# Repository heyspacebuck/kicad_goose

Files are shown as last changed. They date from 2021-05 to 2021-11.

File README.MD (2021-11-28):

# Horrible Goose Badge SAO

[@Gnarflordius](https://twitter.com/Gnarflordius) made a KiCad footprint of the Horrible Goose so I turned it into a set of capacitive-touch boards that function as [Simple Add-Ons](https://hackaday.com/2019/03/20/introducing-the-shitty-add-on-v1-69bis-standard/). All the boards are based on the [Atmel AT42QT101x chips](http://ww1.microchip.com/downloads/en/DeviceDoc/40001947A.pdf), which are out of stock everywhere right now. Sorry. If anyone has suggestions for alternate cap-touch sensors, or knows how to set up QTouch on an ATtiny, please drop me a line.

The `/kicad` folder is set up to contain multiple projects that each rely on `goose.lib` and `\goose.pretty` for schematic symbols and PCB footprints. These projects are:

### SAO 1: Horrible Goose Cap Touch Sensor

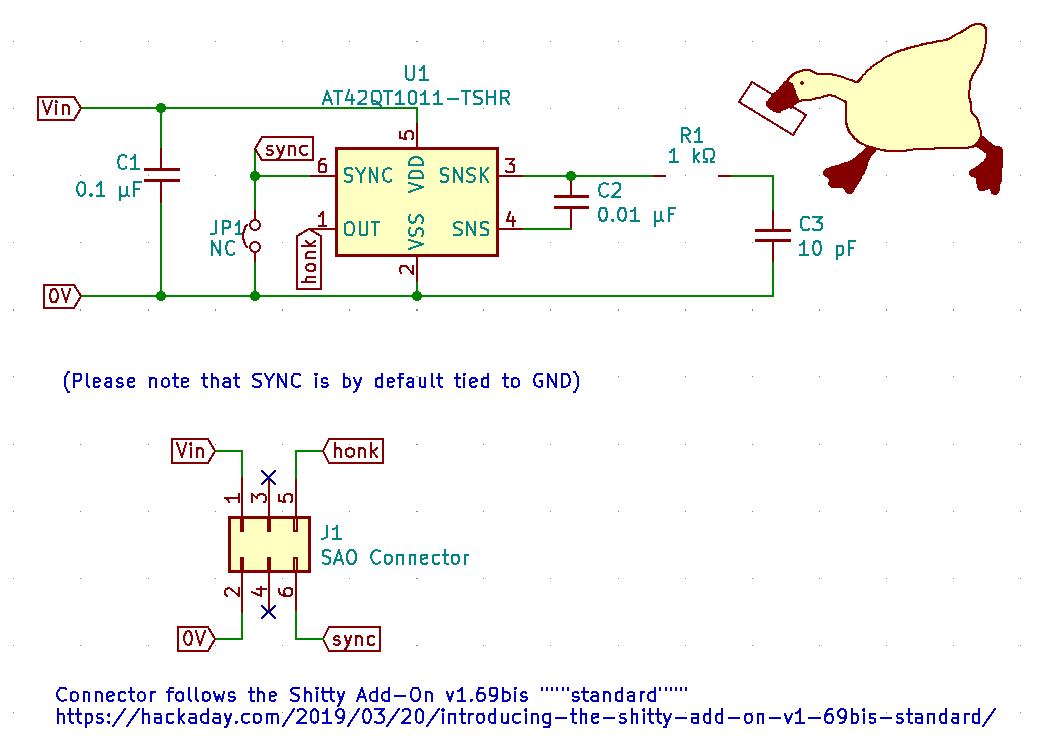
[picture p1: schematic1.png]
schematic

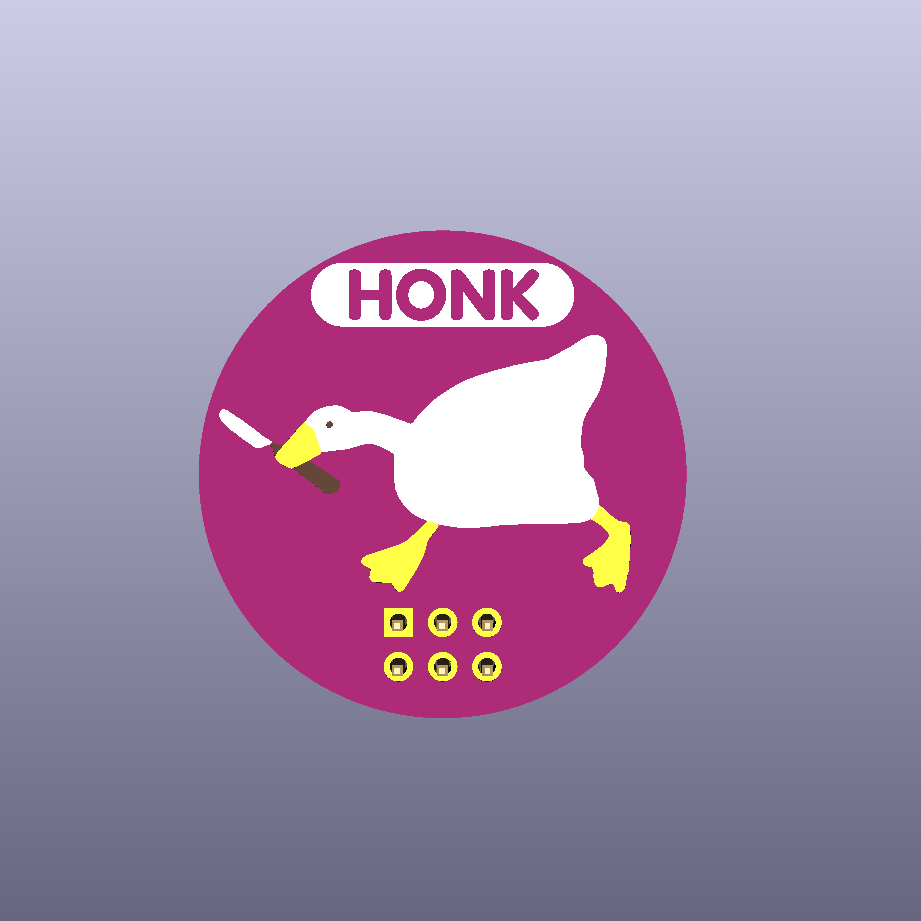
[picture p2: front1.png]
front render

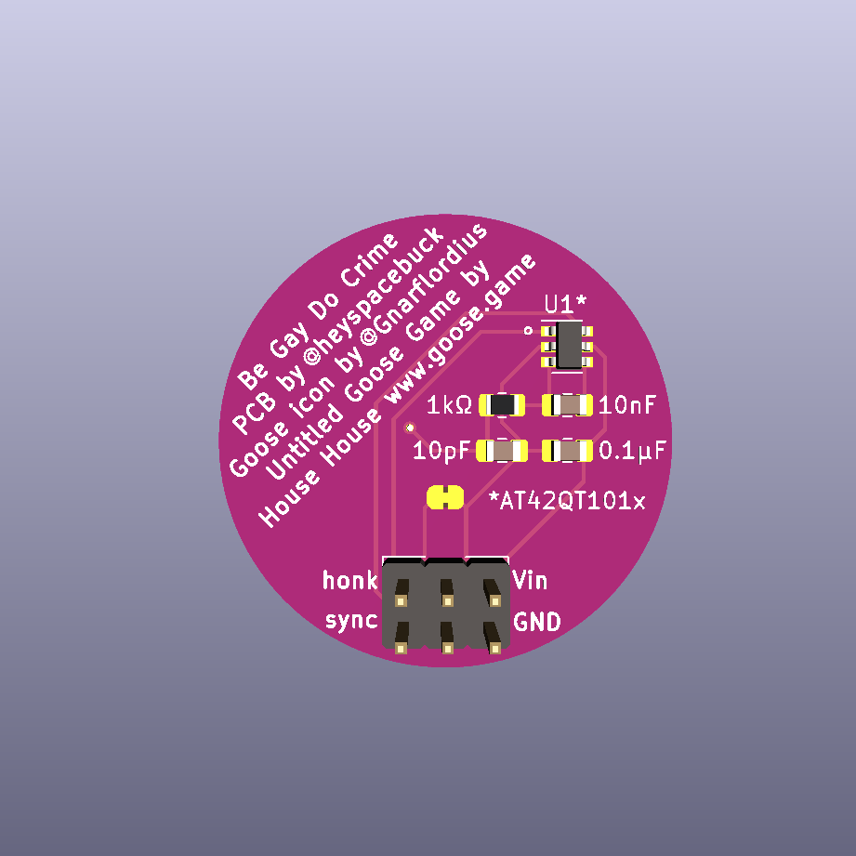
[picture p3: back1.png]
back render

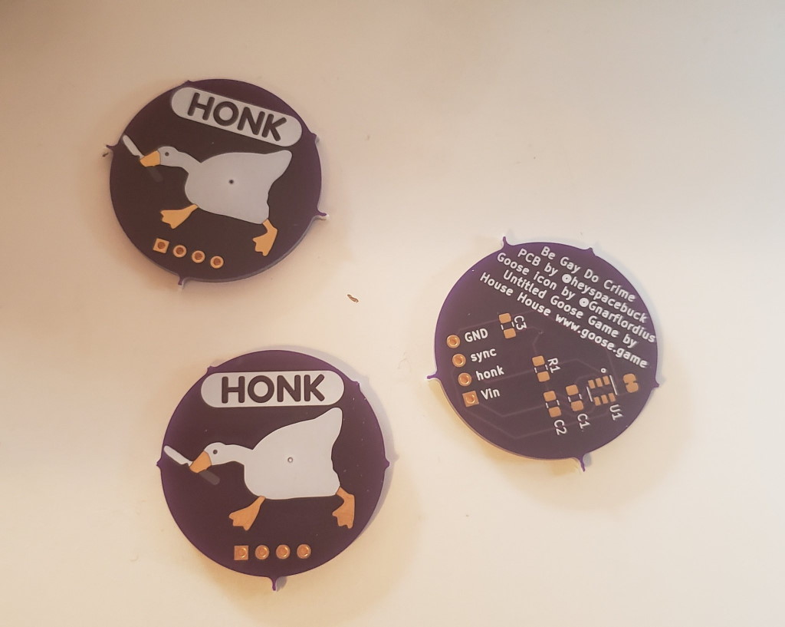
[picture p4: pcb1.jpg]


Here we see the basic SAO. You can find it in the `/kicad` folder under the name `SAO-captouch-sensor-only.pro`. The SCL and SDA lines are not needed; the HONK pin (GPIO1, by SAO naming conventions) connects to the sensor output; the SYNC pin (GPIO2) is by default tied to ground. When the goose is touched, the HONK pin is driven HIGH; otherwise, it is pulled LOW by an internal pull-down resistor. If for whatever reason you want to mess with the default SYNC settings, you can cut the jumper that ties it to ground and instead drive it via GPIO2.

You can see this circuit (with a non-SAO pinout) connected to an Arduino in [this tweet from back in May](https://twitter.com/heyspacebuck/status/1396235318634840066). The Arduino code being used is available in the `/code/arduino_honk` folder.

### SAO 2: Horrible Goose Cap Touch Sensor - After Dark

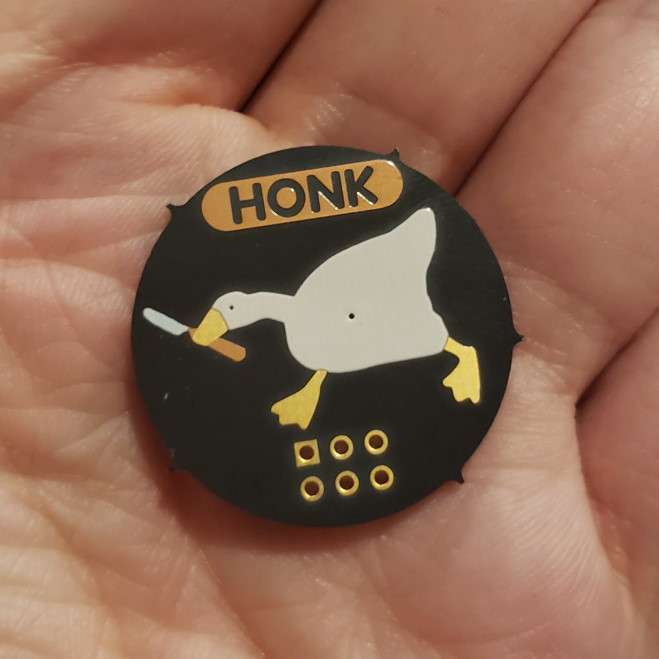
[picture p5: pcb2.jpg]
photo of an OSH Park After Dark PCB


This project is in the `kicad/` folder named `SAO-captouch-sensor-only-after-dark.pro`. It's the same circuit as above, but the "HONK" text and sensor footprint have been optimized for OSH Park's After Dark boards. 

### SAO 3: Horrible Goose, But Extra Evil

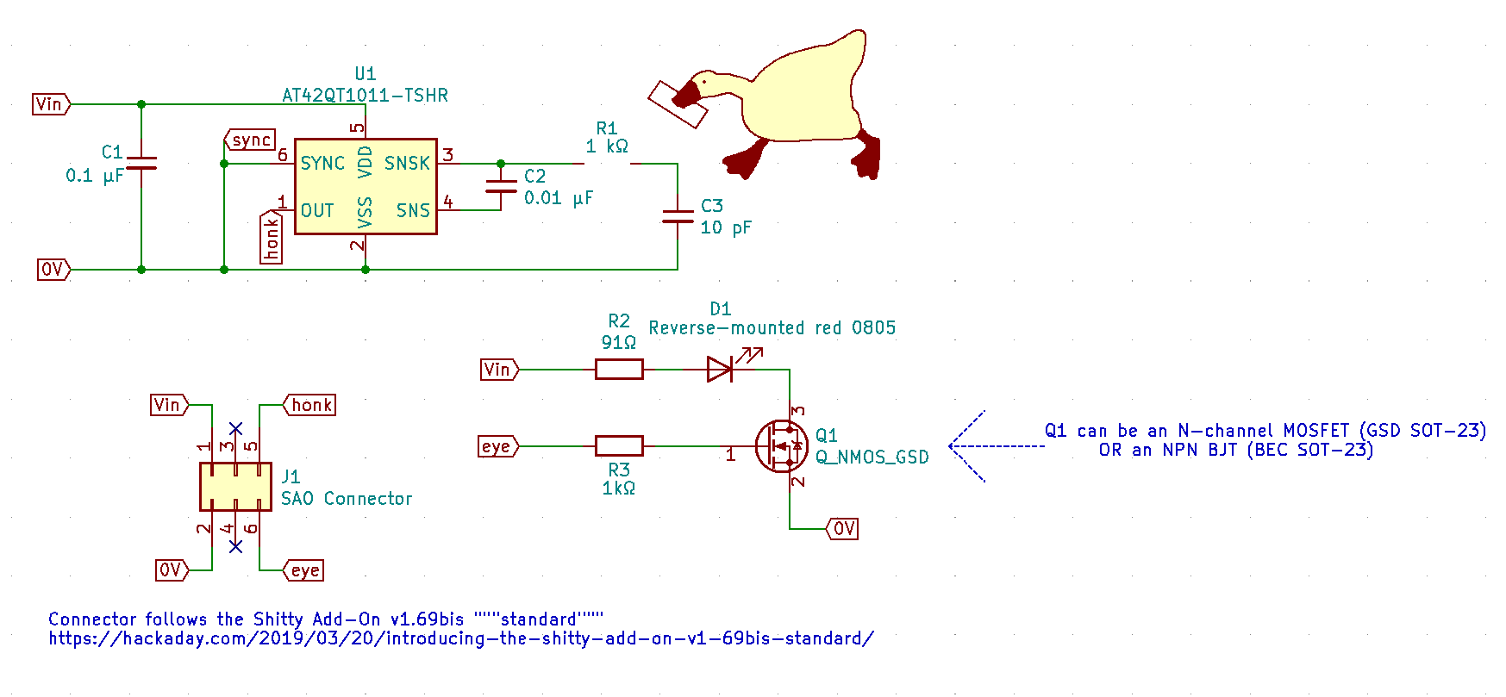
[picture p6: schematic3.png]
schematic

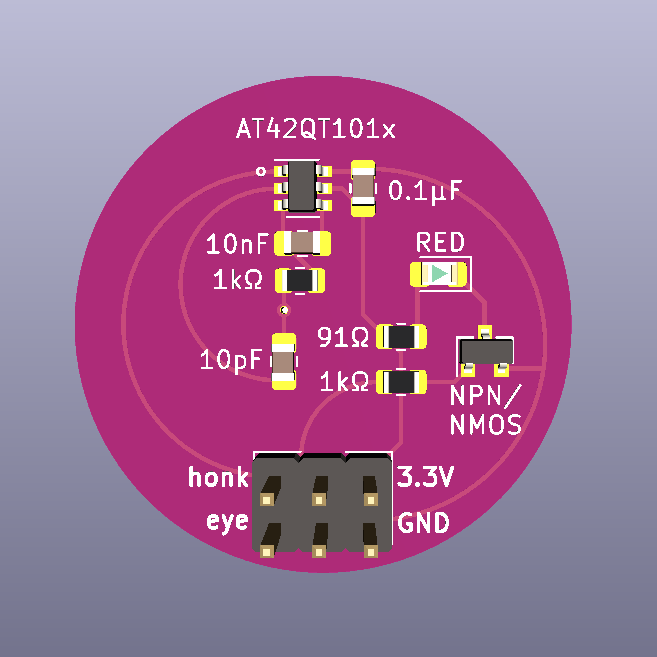
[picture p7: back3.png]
back render

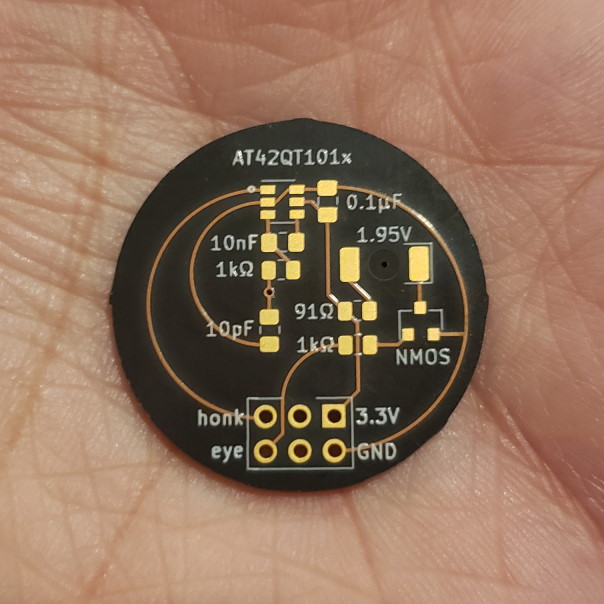
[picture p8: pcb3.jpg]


This project is in the `kicad/` folder named `SAO-captouch-and-eye-after-dark.pro`. Another After Dark board. Similar to the others, but instead of breaking out the SYNC pin, GPIO2 is used to drive a reverse-mounted LED. This makes the goose eye glow and lays bare the true nature of this horrible fowl menacing the village. [You can see it in action (kinda) here](https://twitter.com/heyspacebuck/status/1437613800312610819). KiCad thinks none of the traces are valid because I used graphic arcs instead of normal routing.

### SAO 4: Self-Contained Honking Goose Unit

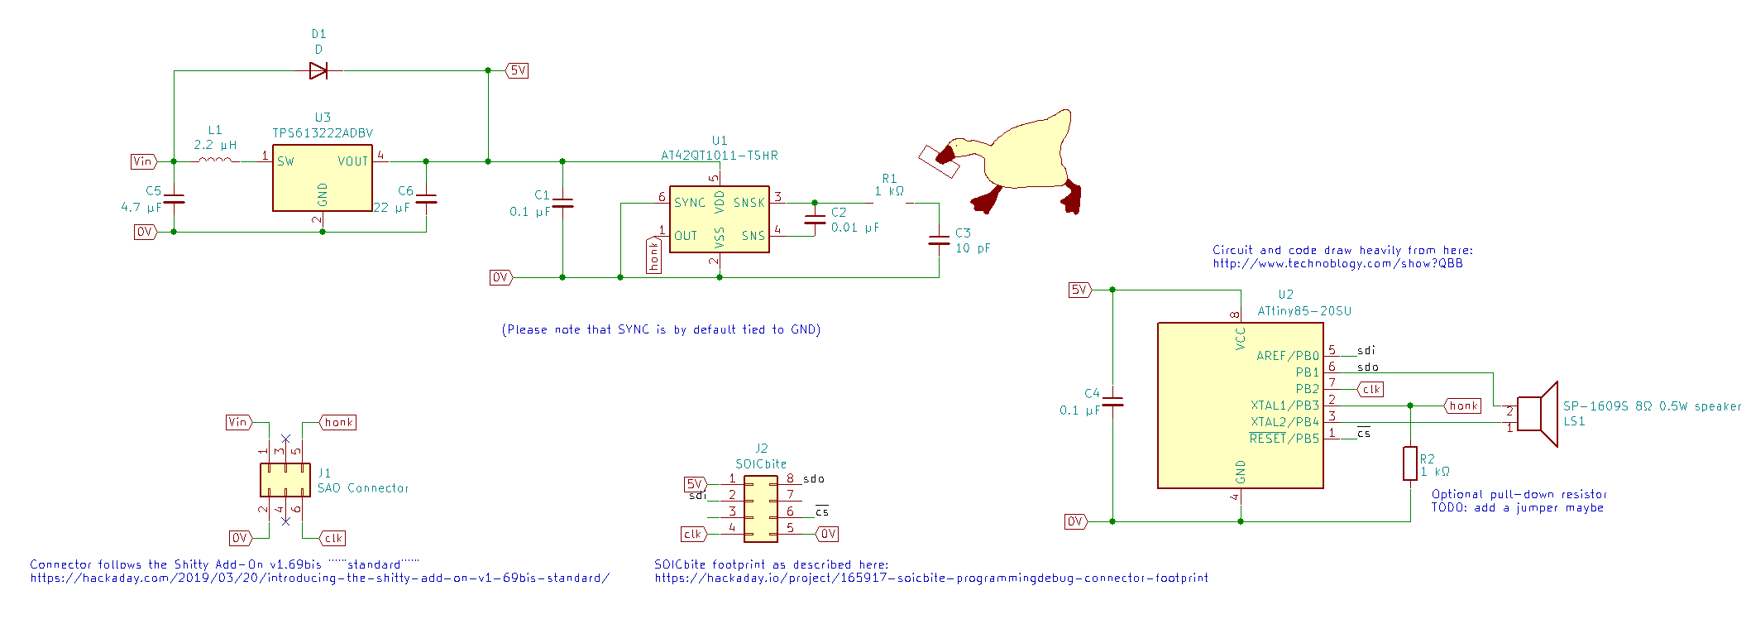
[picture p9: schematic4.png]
schematic

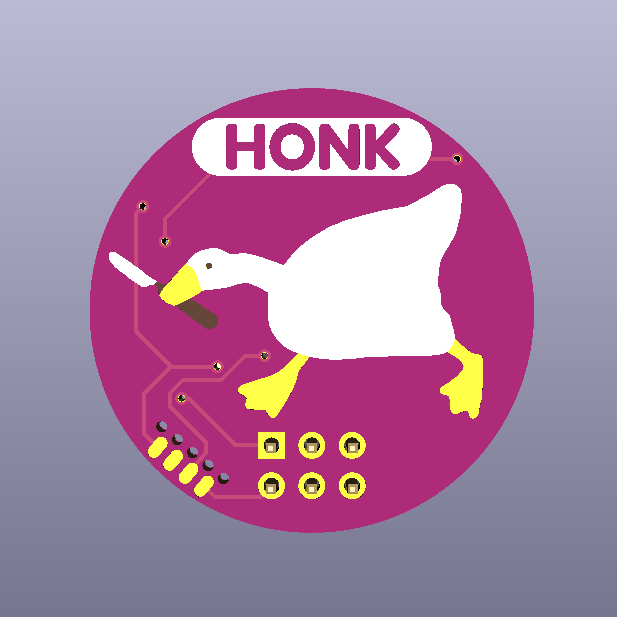
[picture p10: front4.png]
front render

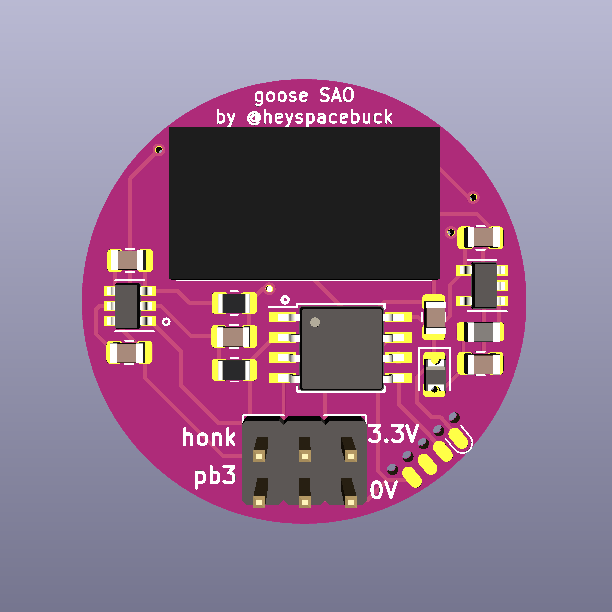
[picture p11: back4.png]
back render

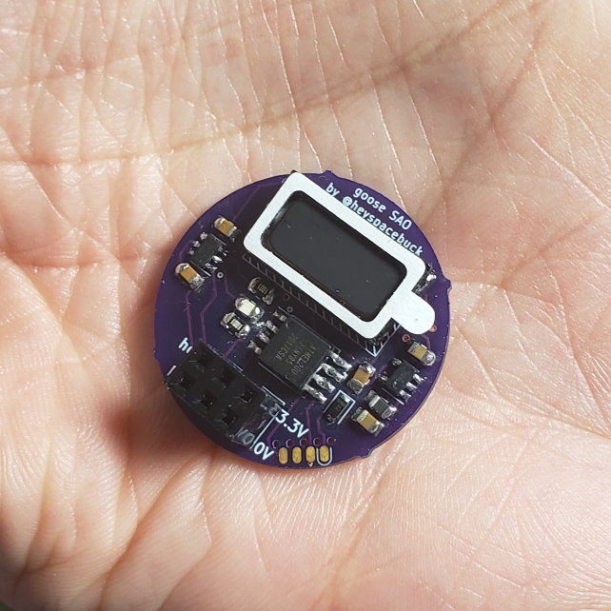
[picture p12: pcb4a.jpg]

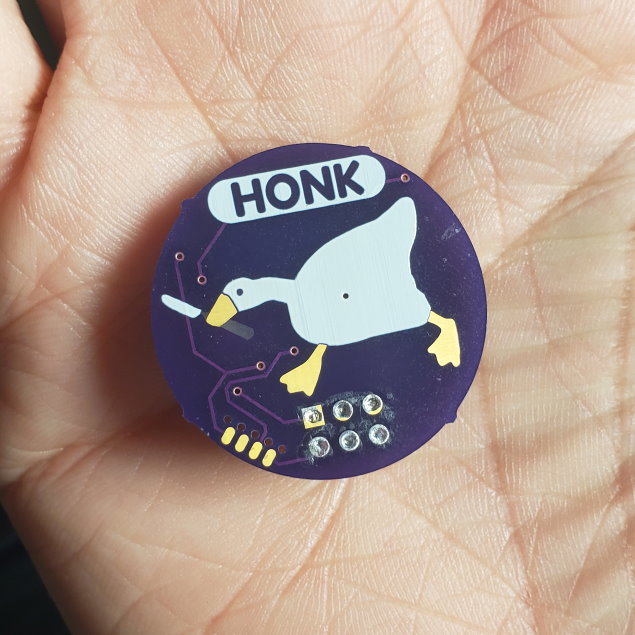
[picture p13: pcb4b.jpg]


This project is in the `kicad/` folder named `SAO-speaker-and-controller.pro`. Once I learned about the existence of extra-small "sugar cube" speakers, I knew I'd have to build an SAO that could function as a standalone honking device. In addition to the cap-touch IC, there's an ATtiny85 driving a 16mm×9mm speaker. Once I got the tiny speaker, it became clear that 3.3V is not sufficient to get an audible honk! I have added a simple boost converter to drive the ATtiny85 and the speaker with 5V instead of 3.3V.

The ATtiny85 is programmed with a [SOICbite connector](https://hackaday.io/project/165917-soicbite-programmingdebug-connector-footprint); if you don't have one it is easy to solder wires to the SOICbite pads. The code is in the `code/tiny85_speaker_control` folder. It's set up for compiling/programming using the Arduino IDE and ATtinyCore approach. You could also use Atmel's QT creator, since the code uses no Arduino-specific methods; just rename `tiny85_speaker_control.ino` to `main.c`.

## Licenses and acknowledgments 

The horrible goose comes from [Untitled Goose Game by House House](https://goose.game/). It's a charming game and you should check it out! The original KiCad goose footprint was designed by [@Gnarflordius](https://twitter.com/Gnarflordius) and released under a [WTFPL license](http://www.wtfpl.net/). I made some minor changes to the footprint and also created a pair of matching schematic symbols. The SAO PCBs and various bits of code are released under the [CERN Open Hardware Licence 1.2](https://en.wikipedia.org/wiki/CERN_Open_Hardware_Licence), but to be honest I'm not sure I'm using it correctly. Do what you want.

The Arduino and ATtiny85 code is derived from two sources: ["Audio Sample Player v2" by David Johnson-Davies](http://www.technoblogy.com/show?QBB) (used under CC-BY-4.0 license), and ["speaker_pcm" by Michael Smith <michael@hurts.ca>](https://playground.arduino.cc/Code/PCMAudio/) (unclear license).

The [SOICbite connector](https://hackaday.io/project/165917-soicbite-programmingdebug-connector-footprint) is an awesome little design from Simon Merrett and is released under the BSD 2-Clause "Simplified" License.

The HONK text was generated using the very cool [KiBuzzard plugin by Greg Davill](https://github.com/gregdavill/KiBuzzard).

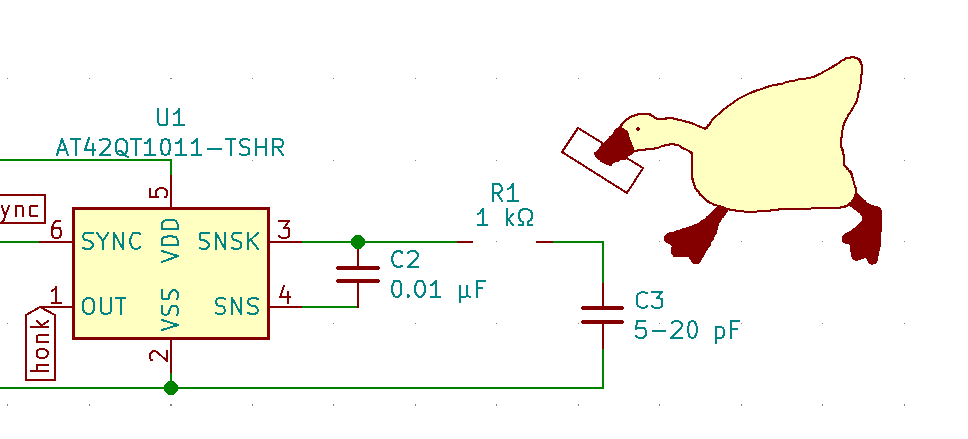
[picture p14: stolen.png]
Schematic with goose stealing a resistor


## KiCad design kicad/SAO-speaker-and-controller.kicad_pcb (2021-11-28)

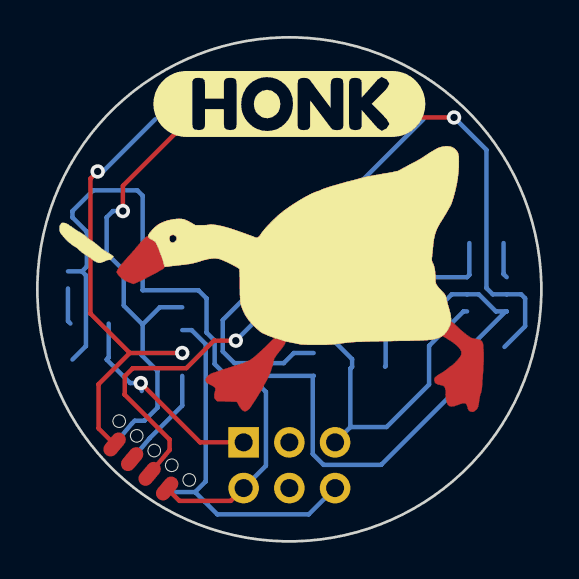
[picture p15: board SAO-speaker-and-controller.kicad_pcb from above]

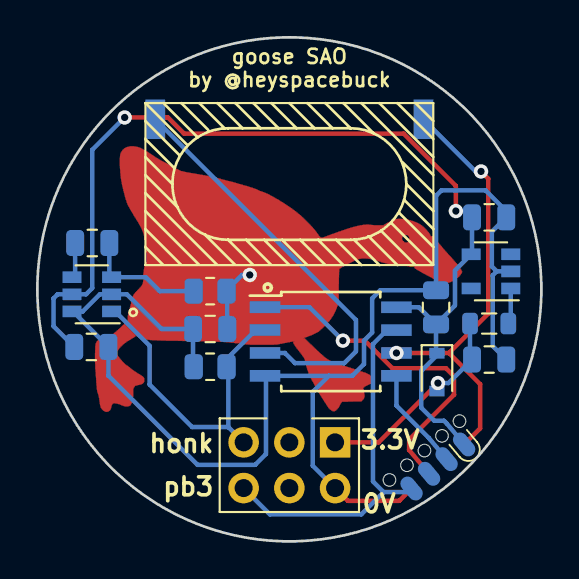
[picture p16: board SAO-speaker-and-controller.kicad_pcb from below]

Board: 2 copper layers, 28.0 x 28.0 mm, 18 parts (16 on the bottom side), 13 nets.

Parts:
C1, C4: 0.1 μF; C_0805_2012Metric
C2: 0.01 μF; C_0805_2012Metric
C3: 10 pF; C_0805_2012Metric
C5: 4.7 μF; C_0805_2012Metric
C6: 22 μF; C_0805_2012Metric
D1: D; D_SOD-323
GOOSE1: LOGO; honk_captouch_scaled_v2
J1: SAO Connector; PinHeader_2x03_P2.54mm_Vertical
J2: SOICbite; SOIC_clipProgSmall
L1: 2.2 μH; L_0805_2012Metric
LS1: SP-1609S 8Ω 0.5W speaker; Speaker_SP-1609S
R1, R2: 1 kΩ; R_0805_2012Metric
U1: AT42QT1011-TSHR; SOT-23-6
U2: ATtiny85-20SU; SOIJ-8_5.3x5.3mm_P1.27mm
U3: TPS613222ADBV; SOT-23-5
svg2mod: G***; label

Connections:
0V: C1.2, C3.2, C4.2, C5.2, C6.2, J1.2, J2.5, R2.1, U1.2, U1.6, U2.4, U3.2
5V: C1.1, C4.1, C6.1, D1.1, J2.1, U1.5, U2.8, U3.4
/sdi: J2.2, U2.5
/sdo: J2.8, LS1.2, U2.6
/~cs: J2.6, U2.1
unnamed: C2.1, R1.1, U1.3
unnamed: C2.2, U1.4
unnamed: C3.1, R1.2
unnamed: L1.2, U3.1
unnamed: LS1.1, U2.3
Vin: C5.1, D1.2, J1.1, L1.1
clk: J1.6, J2.4, U2.7
honk: J1.5, R2.2, U1.1, U2.2

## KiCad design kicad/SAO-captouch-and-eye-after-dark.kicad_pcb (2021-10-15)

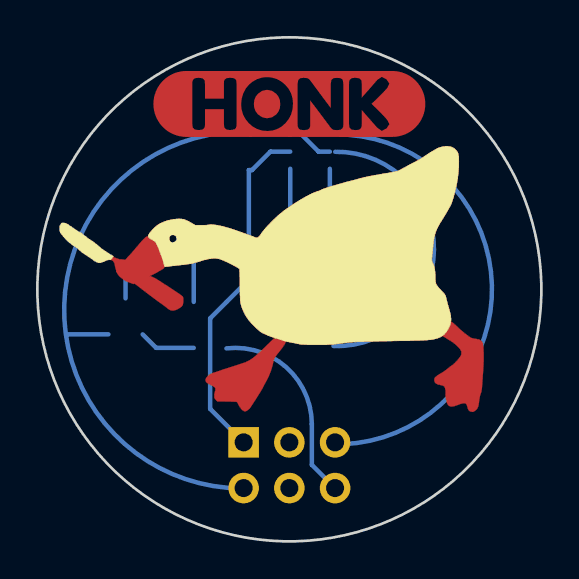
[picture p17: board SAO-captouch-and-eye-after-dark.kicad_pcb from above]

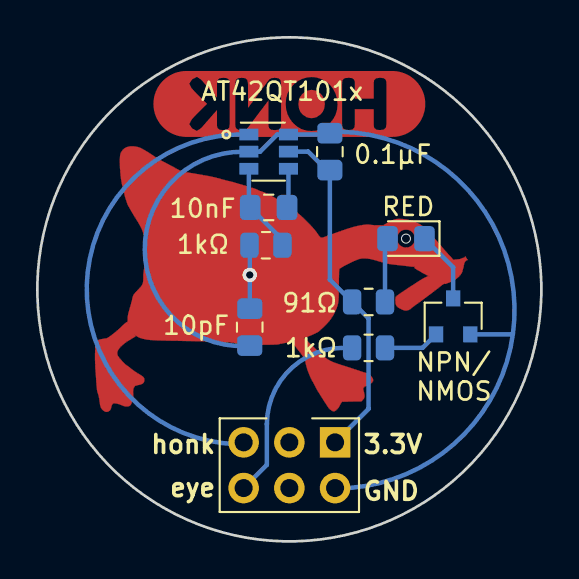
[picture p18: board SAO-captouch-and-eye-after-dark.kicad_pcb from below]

Board: 2 copper layers, 28.0 x 28.0 mm, 12 parts (10 on the bottom side), 10 nets.

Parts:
C1: 0.1 μF; C_0805_2012Metric_Pad1.15x1.40mm_HandSolder
C2: 0.01 μF; C_0805_2012Metric_Pad1.15x1.40mm_HandSolder
C3: 10 pF; C_0805_2012Metric_Pad1.15x1.40mm_HandSolder
D1: Reverse-mounted red 0805; LED_0805_2012Metric_Pad1.15x1.40mm_HandSolder
GOOSE1: LOGO; honk_captouch_scaled_afterdark
J1: SAO Connector; PinHeader_2x03_P2.54mm_Vertical
Q1: Q_NMOS_GSD; SOT-23
R1: 1 kΩ; R_0805_2012Metric
R2: 91Ω; R_0805_2012Metric
R3: 1kΩ; R_0805_2012Metric
U1: AT42QT1011-TSHR; SOT-23-6
svg2mod: G***; label

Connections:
0V: C1.2, C3.2, J1.2, Q1.2, U1.2, U1.6
unnamed: C2.1, R1.1, U1.3
unnamed: C2.2, U1.4
unnamed: C3.1, R1.2
unnamed: D1.1, Q1.3
unnamed: D1.2, R2.1
unnamed: Q1.1, R3.1
Vin: C1.1, J1.1, R2.2, U1.5
eye: J1.6, R3.2
honk: J1.5, U1.1

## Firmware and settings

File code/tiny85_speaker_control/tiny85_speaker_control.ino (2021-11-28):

/*
   Horrible Goose SAO with built-in speaker
   ATtiny85 as controller
   Partly based on "Audio Sample Player v2" by David Johnson-Davies, used under CC-BY-4.0 license: http://www.technoblogy.com/show?QBB
   Partly based on "speaker_pcm" by Michael Smith <michael@hurts.ca>, unclear license: https://playground.arduino.cc/Code/PCMAudio/
*/

#include <avr/sleep.h>
#include <util/delay.h>

// Audio samples encoded as unsigned 8-bit blocks, 16kHz sampling rate
#include "gooseaudio.h"

#define SPEAKER_PIN_1 1            // PB1, pin 6 (if SOIC-8)
#define SPEAKER_PIN_2 4            // PB4, pin 3 (if SOIC-8)
#define INPUT_PIN     3            // PB3, pin 2 (if SOIC-8)

volatile int index = 0;            // Index of current byte of audio data
volatile byte amplitude = 0x80;    // The value of the current byte of audio data.
volatile bool honking = false;     // Monitors if a honk is currently being played, to prevent another one from starting.
volatile bool debouncing = false;  // Monitors if a pin change interrupt was very recently triggered, to prevent triggering signals a few clock cycles apart.
volatile int debounceFrames = 0;   // Counts how many Timer0 interrupts have occurred since the debounce window began.

// Disable Timer/Counter 0 and Timer/Counter 1 to save power
void disableTimers() {
  TCCR0B &= ~(7 << CS00);          // Disable the 16kHz timer (Datasheet p.79)
  TCCR1 &= ~(1 << PWM1A);          // Disable Timer/Counter 1 PWM (Datasheet p.89)
}

// Enable Timer/Counter 0 and Timer/Counter 1
void enableTimers() {
  TCCR0B |= 2 << CS00;             // Enable Timer/Counter 0 with 1/8 prescaler (Datasheet p.79)
  TCCR1 |= 1 << PWM1A;             // Enable Timer/Counter 1 PWM (Datasheet p.89)
}

// Enter low power sleep mode
void sleepyGoose() {
  sei();
  MCUCR |= 1 << SE;                // Enter sleep mode (Datasheet p.37)
  sleep_cpu();
}

// Exit low power sleep mode
void awakeGoose() {
  MCUCR &= ~(1 << SE);             // Wake up from sleep mode (Datasheet p.37)
  cli();
}


void setup() {
  // Enable pin change interrupt (Datasheet p.51-52)
  GIMSK |= 1 << PCIE;              // Pin Change Interrupt enabled
  PCMSK = 1 << PCINT3;             // Pin Change Interrupt occurs only when PB3 (pin 2) changes value

  // Enable Timer/Counter 0, set up to interrupt at 16000 kHz (Datasheet p.77-81)
  TCCR0A = 3 << WGM00;             // Fast PWM mode
  TCCR0B = 1 << WGM02;             // Fast PWM mode
  TCCR0B |= 2 << CS00;             // 1/8 prescaler (1 MHz effective clock speed)
  TIMSK |= 1 << OCIE0A;            // Enable Timer0 Compare Match A Interrupts
  OCR0A = 62;                      // Interrupt every 62 cycles (1/62 MHz == approx. 16 kHz)

  // Enable Timer/Counter 1, generate PWM pulses for the speaker (Datasheet p.89-90)
  TCCR1 = 1 << PWM1A;              // OCR1A PWM enabled
  TCCR1 |= 2 << COM1A0;            // OC1A goes LOW on counter match
  TCCR1 |= 1 << CS10;              // 1/1 prescaler
  GTCCR = 1 << PWM1B;              // OCR1B PWM enabled
  GTCCR |= 2 << COM1B0;            // OC1B goes LOW on counter match
  OCR1A = 128;                     // Set both speaker pins to 50% duty cycle at start
  OCR1B = 128;                     // Set both speaker pins to 50% duty cycle at start

  MCUCR |= 2 << SM0;               // Enable sleep mode to save power (Datasheet p.37)

  DDRB = (1 << DD1) | (1 << DD4);  // Set both speaker pins as outputs
}

void loop() {
  // lol
}

// On a pin change interrupt:
//   Ignore if pin goes LOW, or if we're in the debouncing window, or if a honk is already playing.
//   If none of those conditions AND pin goes HIGH, exit sleep mode, turn on timers, and enter the debouncing window.
ISR(PCINT0_vect) {
  if (!honking && !debouncing && (PINB & (1<<PINB3))) {
    awakeGoose();
    enableTimers();
    debouncing = true;
  }
}

// On a timer 0 interrupt (16000 kHz):
//   If a honk is playing, write the next audio sample to speaker pins.
//   If honk ends, disable timers and go to sleep.
//   If currently in debouncing window, increment the debounce counter.
//   If at the end of the debouncing window, read input pin again.
//   If input pin is still HIGH, begin playing a honk.
ISR(TIMER0_COMPA_vect) {
  if (honking) {
    if (index < 0) {
      // Fade in before playing the actual sound effect, to reduce clicking
      amplitude = 128 + index;
      OCR1A = amplitude;
      OCR1B = amplitude;
    } else if (index < DATA_LENGTH) {
      amplitude = pgm_read_byte(&audio[index]);
      OCR1A = amplitude;
      OCR1B = amplitude ^ 255;
    } else if (index < (DATA_LENGTH + 128)) {
      // Fade out after the sound is done playing
      amplitude = 128 - (index - DATA_LENGTH);
      OCR1A = amplitude;
      OCR1B = amplitude;
    } else {
      honking = false;
      disableTimers();
      sleepyGoose();
    }
    ++index;
  }

  if (debouncing) {
    debounceFrames++;
    if (debounceFrames > 100) {
      debouncing = false;
      debounceFrames = 0;
      if (PINB & (1 << PINB3)) {
        honking = true;
        index = -127;
      }
    }
  }
}

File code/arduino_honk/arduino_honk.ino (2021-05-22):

/*
 * Vector audio playback
 * Taken from speaker_pcm sketch by Michael Smith <michael@hurts.ca>
 * available here: https://playground.arduino.cc/Code/PCMAudio/
 */

#include "gooseaudio.h"

#include <stdint.h>
#include <avr/interrupt.h>
#include <avr/io.h>
#include <avr/pgmspace.h>

int SAMPLE_RATE = 16000;
int SPEAKER_PIN = 11;
int TOUCH_PIN = 8;

volatile uint16_t sample;
byte lastSample;

bool honking = false;

void stopPlayback()
{
  // Disable playback per-sample interrupt.
  TIMSK1 &= ~_BV(OCIE1A);

  // Disable the per-sample timer completely.
  TCCR1B &= ~_BV(CS10);

  // Disable the PWM timer.
  TCCR2B &= ~_BV(CS10);

  digitalWrite(SPEAKER_PIN, LOW);
  honking = false;
}

// This is called at 16000 Hz to load the next sample.
ISR(TIMER1_COMPA_vect) {
  if (sample >= DATA_LENGTH) {
    if (sample == DATA_LENGTH + lastSample) {
      stopPlayback();
    }
    else {
      if(SPEAKER_PIN==11){
        // Ramp down to zero to reduce the click at the end of playback.
        OCR2A = DATA_LENGTH + lastSample - sample;
      } else {
        OCR2B = DATA_LENGTH + lastSample - sample;                
      }
    }
  }
  else {
    if(SPEAKER_PIN==11){
      OCR2A = pgm_read_byte(&audio[sample]);
    } else {
      OCR2B = pgm_read_byte(&audio[sample]);            
    }
  }

  ++sample;
}


void honk()
{
  pinMode(SPEAKER_PIN, OUTPUT);

  // Set up Timer 2 to do pulse width modulation on the speaker pin.

  // Use internal clock (datasheet p.160)
  ASSR &= ~(_BV(EXCLK) | _BV(AS2));

  // Set fast PWM mode  (p.157)
  TCCR2A |= _BV(WGM21) | _BV(WGM20);
  TCCR2B &= ~_BV(WGM22);

  if(SPEAKER_PIN==11){
    // Do non-inverting PWM on pin OC2A (p.155)
    // On the Arduino this is pin 11.
    TCCR2A = (TCCR2A | _BV(COM2A1)) & ~_BV(COM2A0);
    TCCR2A &= ~(_BV(COM2B1) | _BV(COM2B0));
    // No prescaler (p.158)
    TCCR2B = (TCCR2B & ~(_BV(CS12) | _BV(CS11))) | _BV(CS10);

    // Set initial pulse width to the first sample.
    OCR2A = pgm_read_byte(&audio[0]);
  } else {
    // Do non-inverting PWM on pin OC2B (p.155)
    // On the Arduino this is pin 3.
    TCCR2A = (TCCR2A | _BV(COM2B1)) & ~_BV(COM2B0);
    TCCR2A &= ~(_BV(COM2A1) | _BV(COM2A0));
    // No prescaler (p.158)
    TCCR2B = (TCCR2B & ~(_BV(CS12) | _BV(CS11))) | _BV(CS10);

    // Set initial pulse width to the first sample.
    OCR2B = pgm_read_byte(&audio[0]);
  }

  // Set up Timer 1 to send a sample every interrupt.
  cli();

  // Set CTC mode (Clear Timer on Compare Match) (p.133)
  // Have to set OCR1A *after*, otherwise it gets reset to 0!
  TCCR1B = (TCCR1B & ~_BV(WGM13)) | _BV(WGM12);
  TCCR1A = TCCR1A & ~(_BV(WGM11) | _BV(WGM10));

  // No prescaler (p.134)
  TCCR1B = (TCCR1B & ~(_BV(CS12) | _BV(CS11))) | _BV(CS10);

  // Set the compare register (OCR1A).
  // OCR1A is a 16-bit register, so we have to do this with
  // interrupts disabled to be safe.
  OCR1A = F_CPU / SAMPLE_RATE;    // 16e6 / 8000 = 2000

  // Enable interrupt when TCNT1 == OCR1A (p.136)
  TIMSK1 |= _BV(OCIE1A);

  lastSample = pgm_read_byte(&audio[DATA_LENGTH-1]);
  sample = 0;
  sei();
}

void setup() {
  //Serial.begin(115200);
  //honk();
}

void loop() {
  if (!honking && digitalRead(TOUCH_PIN)) {
    honking = true;
    honk();
  }
}

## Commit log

2021-05-09 Init commit
    [goose.kicad_pcb, goose.sch]
2021-05-09 Fixed jumper soldermask
    [goose.kicad_pcb]
2021-05-10 added resistor-stealing goose schematic symbol
    [goose.sch]
2021-05-22 Added Arduino sketch
2021-05-22 Update readme and goose_R library symbol
    [goose.kicad_pcb]
2021-08-23 Changed to SAO connector
    [goose.kicad_pcb, goose.sch]
2021-10-15 Dramatic restructuring
    [SAO-captouch-and-eye-after-dark.kicad_pcb, SAO-captouch-and-eye-after-dark.sch, SAO-captouch-sensor-only-after-dark.kicad_pcb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]
2021-11-28 Update design 4
    [SAO-speaker-and-controller.kicad_pcb, SAO-speaker-and-controller.sch]
